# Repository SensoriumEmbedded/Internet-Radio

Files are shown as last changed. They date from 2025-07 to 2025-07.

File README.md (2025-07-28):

# Internet-Radio
ESP32 based WiFi Internet Radio with display, rotary encoder controls, and SD storage

## Stand-alone version:
|||
|--|--|
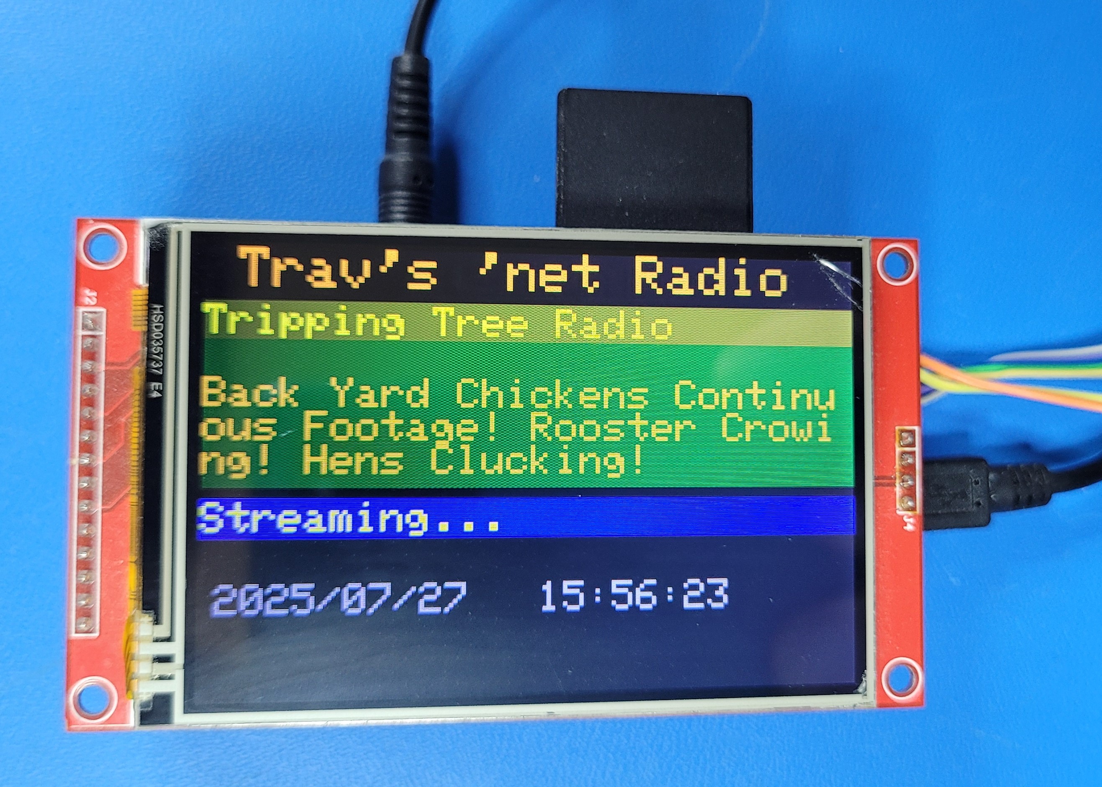
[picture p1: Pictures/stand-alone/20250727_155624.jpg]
Stand-alone front
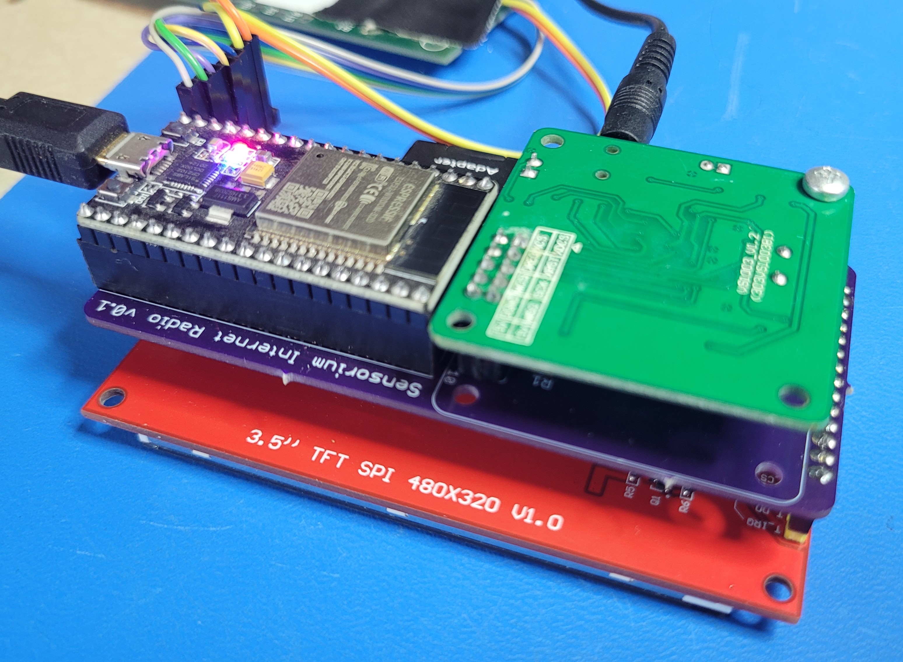
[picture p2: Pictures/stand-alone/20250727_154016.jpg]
Stand-alone back
|||

## Full version incorporated in a 1941 Philco Radio case:
|||
|--|--|
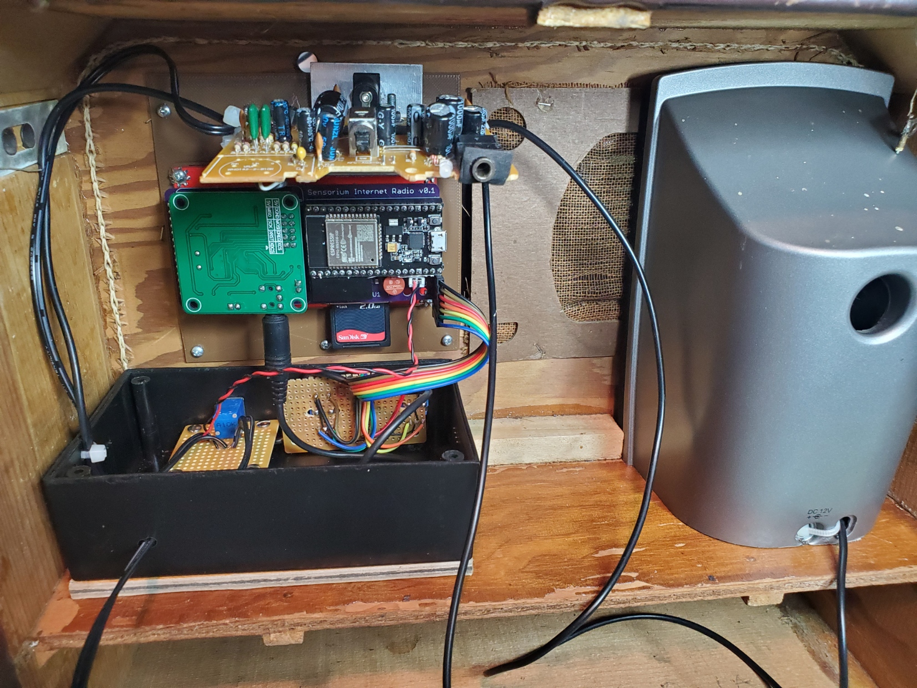
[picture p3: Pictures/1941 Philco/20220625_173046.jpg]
|<video src="Pictures/1941 Philco/Internet Radio_01.mp4" title="1941 Philco project"></video>||

<video controls src="Pictures/1941 Philco/Internet Radio_01.mp4" title="Title"></video>

## Features
* Plays streaming MP3 stations
  * Large buffer for smooth playback
* Parses/displays displays meta data information
* Stores settings and favorite stations on SD card
* Can display pictures (jpg) and play MP3 files
* Displays time, synched from internet connection
* Remote control interface via TTL serial

## Operation
* "S" Rotary Encoder: Push to enter menu system/select.  Rotate to move "cursor"
* "C" Rotary Encoder: Turn (slowly) to select channels, like a dial.  push to stop streaming.
* Scan for wifi and enter a PW in the menu (among other things, explore away).
  * All the settings are saved to "NetRadio.txt" on the SD card. 

## Inspiration
* https://github.com/Edzelf/Esp-radio
* https://github.com/RalphBacon/205-Internet-Radio

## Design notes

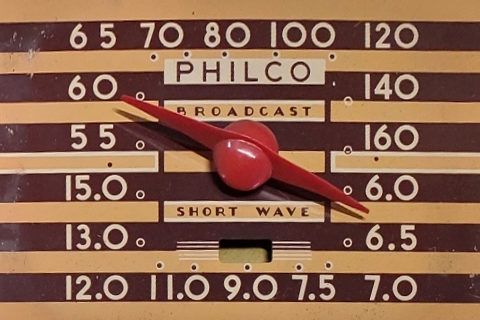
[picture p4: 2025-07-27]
Source/SD Card/DialOnly.jpg

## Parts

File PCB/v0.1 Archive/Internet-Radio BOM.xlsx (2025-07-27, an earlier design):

Part | Value | Source for June 2022 build | Description | DIGIKEY | MANUF1 | MPN1
Required for min config, USB powered:
J2 | VS1053 CoDec | Amazon | HiLetgo VS1053 MP3 Audio Player Module Audio Decoder | Amazon (https://www.amazon.com/HiLetgo-Recording-Microphone-Interface-12-288Mhz/dp/B07XCN3C7B) |  |  | $11.39
J4 | ESP32 | Amazon | HiLetgo ESP-WROOM-32 ESP3 | Amazon (https://www.amazon.com/HiLetgo-ESP-WROOM-32-Development-Microcontroller-Integrated/dp/B0718T232Z) |  |  | $9.99
J5 | TFT Display | Amazon | LCD Screen Module TFT 3.5 inch SPI Serial 480 x 320 ILI9488 | Amazon (https://www.amazon.com/Module-3-5inch-ILI9488-Electronic-Accessories/dp/B08DKNLSNX) | Amazon 2 (https://www.amazon.com/Hosyond-Display-Compatible-Mega2560-Development/dp/B0BWJHK4M6?th=1) |  | $16.99
PBC | PCB v0.1 | OSH Park | Sensorium Internet Radio v0.1
J2-5 | Female Headers | stock | 2x5 and 1x(14+4+19+19=56) female headers
J5b | Male Header | stock | 1x4, solder to display
 | SD Card | stock |  |  |  |  | $3.60
 | Rot Encoders | Digikey |  | Amazon (https://www.amazon.com/WWZMDiB-Encoder-Digital-Potentiometer-Arduino/dp/B0C6Q67V97) | ACZ11BR1E-20FD1-12C | CUI Devices | $2.96
Optional for 9-18Vin external power supply. Includes isolation so same source supply can be used for amp/speakers
C1 | 0.1 uF | stock | Cap, 0805
C2 | 10 uF, 25v | stock | Cap, 0805 | 1276-2890-1-ND
C3 | 47 uF | Mouser | Cap, 0805
D1 | CUS08F30 | Mouser | DIODE SCHOTTKY 30V 800MA USC SOD-323 | CUS08F30H3FTR-ND | Toshiba | CUS08F30,H3F
F1 | 500mA | stock | 500mA Fuse | WK4041BK-ND | Littelfuse Inc | 37405000410
J1 | JST-2POS-2MM | stock | CONN HEADER VERT 2POS 2MM | 455-1704-ND | JST Sales America Inc. | B2B-PH-K-S(LF)(SN)
J3 | 5 pin header | n/a | FEMALE HEADER
R1 | DNS | n/a | Resistor, 0805
U1 | SPAN02A-05 | Mouser | Isolated DC/DC conv

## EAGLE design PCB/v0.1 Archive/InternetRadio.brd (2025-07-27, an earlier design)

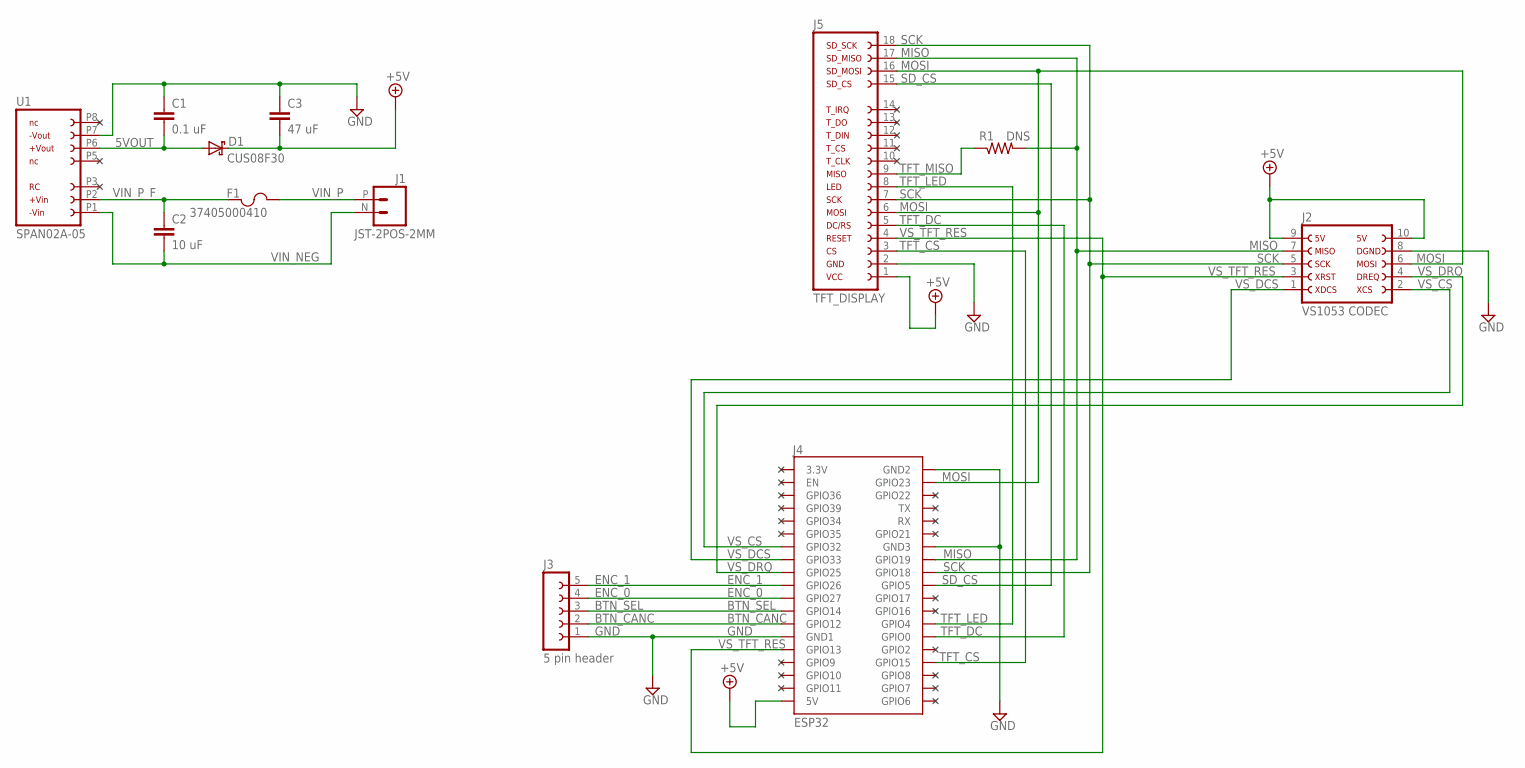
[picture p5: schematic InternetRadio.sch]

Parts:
C1: 0.1 uF; 0805
C2: 10 uF; 0805
C3: 47 uF; 0805
D1: CUS08F30; SOD-323
F1: 37405000410; FUS_LITTELFUSE_374_LTF
J1: JST-2POS-2MM; 89400-0220
J2: VS1053 CODEC; VS1053_MODULE
J3: 5 pin header; FE05-1
J4: ESP32
J5: TFT_DISPLAY; 3.5"_TFT_DISPLAY-NO_HOLES
R1: DNS; 0805
U1: SPAN02A-05

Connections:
5VOUT: C1.2, D1.A, U1.P6 (6)
+5V: C3.2, D1.C, J2.9, J2.10, J4.5V, J5.1
BTN_CANC: J3.2, J4.GPIO12
BTN_SEL: J3.3, J4.GPIO14
ENC_0: J3.4, J4.GPIO27
ENC_1: J3.5, J4.GPIO26
GND: C1.1, C3.1, J2.8, J3.1, J4.GND1, J4.GND2, J4.GND3, J5.2, U1.P7 (7)
MISO: J2.7, J4.GPIO19, J5.17, R1.2
MOSI: J2.6, J4.GPIO23, J5.6, J5.16
SCK: J2.5, J4.GPIO18, J5.7, J5.18
SD_CS: J4.GPIO5, J5.15
TFT_CS: J4.GPIO15, J5.3
TFT_DC: J4.GPIO0, J5.5
TFT_LED: J4.GPIO4, J5.8
TFT_MISO: J5.9, R1.1
VIN_NEG: C2.2, J1.N (1), U1.P1 (1)
VIN_P: F1.1, J1.P (2)
VIN_P_F: C2.1, F1.2, U1.P2 (2)
VS_CS: J2.2, J4.GPIO32
VS_DCS: J2.1, J4.GPIO33
VS_DRQ: J2.4, J4.GPIO25
VS_TFT_RES: J2.3, J4.GPIO13, J5.4

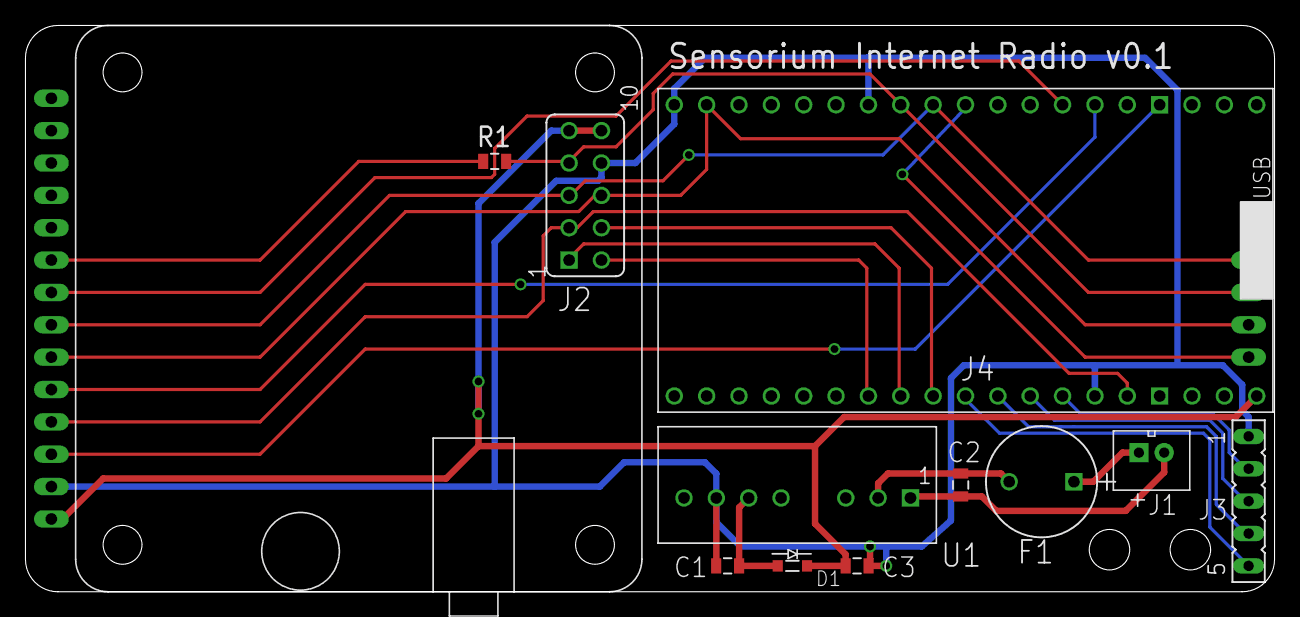
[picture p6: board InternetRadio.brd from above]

Board: 2 copper layers, 98.0 x 44.5 mm, 12 parts (1 on the bottom side), 22 nets.

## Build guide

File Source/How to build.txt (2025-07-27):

How to Build:

  Arduino IDE, v2.3.2 was last used, newer should be fine.
  
  Libraries are included to preserve revision and modification of TFT_eSPI:
   Set sketchbook (lib) location to Source folder (contains /libraries)
  
  Additional board manager:  https://dl.espressif.com/dl/package_esp32_index.json   -or-
                             https://raw.githubusercontent.com/espressif/arduino-esp32/gh-pages/package_esp32_index.json

  Board: "ESP32 Dev Module" (near top of list)  (was NodeMCU-32S)

  7/27/2025 lib info:
    Using library SPI at version 3.0.4 in folder: C:\Users\trav\AppData\Local\Arduino15\packages\esp32\hardware\esp32\3.0.4\libraries\SPI 
    Using library TFT_eSPI at version 2.4.61 in folder: D:\MyData\Geek Stuff\Projects\Internet Radio\Internet-Radio\Source\libraries\TFT_eSPI-2.4.61 
    Using library FS at version 3.0.4 in folder: C:\Users\trav\AppData\Local\Arduino15\packages\esp32\hardware\esp32\3.0.4\libraries\FS 
    Using library SPIFFS at version 3.0.4 in folder: C:\Users\trav\AppData\Local\Arduino15\packages\esp32\hardware\esp32\3.0.4\libraries\SPIFFS 
    Using library VS1053 Library for ESP8266/ESP32 at version 1.1.2 in folder: D:\MyData\Geek Stuff\Projects\Internet Radio\Internet-Radio\Source\libraries\ESP_VS1053_Library 
    Using library WiFi at version 3.0.4 in folder: C:\Users\trav\AppData\Local\Arduino15\packages\esp32\hardware\esp32\3.0.4\libraries\WiFi 
    Using library Networking at version 3.0.4 in folder: C:\Users\trav\AppData\Local\Arduino15\packages\esp32\hardware\esp32\3.0.4\libraries\Network 
    Using library Time at version 1.6.1 in folder: D:\MyData\Geek Stuff\Projects\Internet Radio\Internet-Radio\Source\libraries\Time 
    Using library Bounce2 at version 2.57 in folder: D:\MyData\Geek Stuff\Projects\Internet Radio\Internet-Radio\Source\libraries\Bounce2 
    Using library RotaryEncoder at version 1.5.2 in folder: D:\MyData\Geek Stuff\Projects\Internet Radio\Internet-Radio\Source\libraries\RotaryEncoder 
    Using library SD at version 3.0.4 in folder: C:\Users\trav\AppData\Local\Arduino15\packages\esp32\hardware\esp32\3.0.4\libraries\SD 
    Using library TJpg_Decoder at version 1.0.5 in folder: D:\MyData\Geek Stuff\Projects\Internet Radio\Internet-Radio\Source\libraries\TJpg_Decoder 
    Using library LittleFS at version 3.0.4 in folder: C:\Users\trav\AppData\Local\Arduino15\packages\esp32\hardware\esp32\3.0.4\libraries\LittleFS 
    "C:\\Users\\trav\\AppData\\Local\\Arduino15\\packages\\esp32\\tools\\esp-x32\\2302/bin/xtensa-esp32-elf-size" -A "C:\\Users\\trav\\AppData\\Local\\Temp\\arduino\\sketches\\2D6387340B86BC38645DDF778E6259B7/InternetRadio.ino.elf"
    Sketch uses 1066773 bytes (81%) of program storage space. Maximum is 1310720 bytes.
    Global variables use 124436 bytes (37%) of dynamic memory, leaving 203244 bytes for local variables. Maximum is 327680 bytes.

  Modified for ILI9488_DRIVER, but HX8357D_DRIVER can be used:
    Set Driver in libraries\TFT_eSPI\User_Setup.h
      (comment out one display)
      #define HX8357D_DRIVER   //$40 Blue Adafruit board used on hardwired proto     https://www.adafruit.com/product/2050
      #define ILI9488_DRIVER   //$25 Red board from Amazon     https://www.amazon.com/dp/B08MQLSCRP
      (Pin updates when updating library)
      #define TFT_MISO 19
      #define TFT_MOSI 23
      #define TFT_SCLK 18
      #define TFT_CS   15  // Chip select control pin
      #define TFT_DC    0  //2  // Data Command control pin
      //#define TFT_RST   4  // Reset pin (could connect to RST pin)
      #define TFT_RST  -1  // Set TFT_RST to -1 if display RESET is connected to ESP32 board RST

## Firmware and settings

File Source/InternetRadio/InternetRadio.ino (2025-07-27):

#include <SPI.h>
#include <TFT_eSPI.h>
#include <VS1053.h>
#include <WiFi.h>
#include <TimeLib.h>
#include <WiFiUdp.h>
#include <Bounce2.h>
#include <RotaryEncoder.h>
#include <FS.h>
#include <SD.h>
#include <TJpg_Decoder.h>
#include "InternetRadio.h"

uint32_t LastUpdateMs = millis();
uint16_t StationSelect = 0;
uint16_t BytesUntilMetaData = 0;
uint16_t MetaDataInterval = 0;
char TrackName[MAX_TITLE_LEN] = "";  
bool PrintUpdates = false;  //print periodic updates to USB
bool isStreaming = false;  //Are we Streaming currently?
bool MetaDataPresent = false;    //Meta Data detected in Stream
bool ReConnect = false; //force re-connect from main loop
bool ForceRebuf = false; //force rebuffer on under-run
IPAddress ntpServerIP; // NTP server's ip address, resolved from name at WiFi connect

//these are populated from SD card "/NetRadio.txt" file
char ntpServerName[32] = "us.pool.ntp.org";  // NetTimeProtocol Server name
int timeZone = -7;  //Pacific Daylight Time (USA)
char WiFiSSID[MAX_SSID_CHAR_LEN];
char WiFiPassword[MAX_CHAR_INP_LEN];
StructStationInfo RadioStation[MAX_STATIONS] = {"1940s/50s Radio Retro","64.150.176.42",8098,"/"};
uint16_t NumStations = 1;   // # stations stored
uint16_t CurrentStationNum = 0;  //current station
uint16_t DefaultStationNum = 0;  //Default station
StructStationInfo CurrentStation = RadioStation[CurrentStationNum];

WiFiUDP Udp;
TFT_eSPI tft = TFT_eSPI();
VS1053 player(VS1053_CS_PIN, VS1053_DCS_PIN, VS1053_DREQ_PIN);
WiFiClient client; // Use WiFiClient class to create HTTP/TCP connection
Bounce2::Button SelectButton = Bounce2::Button();
Bounce2::Button CancelButton = Bounce2::Button();

//RotaryEncoder Constructor sets INPUT_PULLUPs
#ifdef PHILCO_1941_RADIO_HW
   RotaryEncoder RotEncSel(ROT_ENC_SEL_1_PIN, ROT_ENC_SEL_0_PIN, RotaryEncoder::LatchMode::FOUR3);
   RotaryEncoder RotEncCanc(ROT_ENC_CANC_0_PIN, ROT_ENC_CANC_1_PIN, RotaryEncoder::LatchMode::FOUR3);
#else
   RotaryEncoder RotEncSel(ROT_ENC_SEL_0_PIN, ROT_ENC_SEL_1_PIN, RotaryEncoder::LatchMode::TWO03);
   RotaryEncoder RotEncCanc(ROT_ENC_CANC_0_PIN, ROT_ENC_CANC_1_PIN, RotaryEncoder::LatchMode::TWO03);
#endif

void setup() 
{
  pinMode(BLUE_LED_PIN, OUTPUT);
  digitalWrite(BLUE_LED_PIN, true); //I'm alive!
  Serial.begin(115200);

  Serial.println("\n\nTrav's ESP32/VS1053 Internet Radio");

  pinMode(VS_TFT_RESET_PIN, OUTPUT);
  digitalWrite(VS_TFT_RESET_PIN, false); //Place the VS1053 and TFT display in reset
  //Drive CS LInes of all SPI devices (except TFT disp) high
  pinMode(VS1053_CS_PIN, OUTPUT);
  digitalWrite(VS1053_CS_PIN, true); 
  pinMode(VS1053_DCS_PIN, OUTPUT); 
  digitalWrite(VS1053_DCS_PIN, true); 
  pinMode(SD_CARD_CS_PIN, OUTPUT); 
  digitalWrite(SD_CARD_CS_PIN, true); 
  delay(10);
  digitalWrite(VS_TFT_RESET_PIN, true); //Release reset

  SPI.begin();

  pinMode(TFT_BACKLIGHT_PIN, OUTPUT); 
  analogWrite(TFT_BACKLIGHT_PIN, 255); //max brightness
  DispInit(); //First SPI dev to init

  player.begin();
  while (!player.isChipConnected()) 
  {
     DispStatus("Couldn't find VS1053");
     player.begin();
     delay(100);
  }
  DispStatus("VS1053 Found");
  
  SDInit(); //todo:  verify success, SD is required
  SDLoadSettings();
  CurrentStationNum = DefaultStationNum;
  CurrentStation = RadioStation[DefaultStationNum];

  SelectButton.attach(SELECT_BUTTON_PIN ,  INPUT_PULLUP); // USE INTERNAL PULL-UP
  SelectButton.interval(5); 
  SelectButton.setPressedState(LOW); 
  CancelButton.attach(CANCEL_BUTTON_PIN ,  INPUT_PULLUP); // USE INTERNAL PULL-UP
  CancelButton.interval(5); 
  CancelButton.setPressedState(LOW); 

  Serial.println("ESP32 Internet Radio");
  Serial.println(VERSION);
  Serial.println("Setup Complete");  
  DispStatus("Setup Complete");  
  digitalWrite(BLUE_LED_PIN, false); // indicates streaming
  
#if SLAVE_MODE
  SerialSlave.begin(115200, SERIAL_8N1, SERIAL2_RXD, SERIAL2_TXD);
  Serial.println("\n*** Slave mode, will not respond to USB Serial commands!");
#else 
  if (WifiConnectDefault()) StreamConnectLoop(); //connect/stream automatically in normal mode
  Serial.println("\nNormal/USB command mode");
#endif

}

void loop()
{ //should be no menu displayed when looping at this top level
  MainLoopWork();

  SelectButton.update();
  if (SelectButton.pressed()) MenuMain();

  CancelButton.update();
  if (CancelButton.pressed()) StopStreaming();  //with no menu, cancel stops streaming
  
  int8_t RotEncCancMove = RotEncCancUpdate();
  if (RotEncCancMove) 
  {  //cancel encoder selects stations
     if (RotEncCancMove == 1)
     {
        if (CurrentStationNum == NumStations - 1) CurrentStationNum = 0; //circular
        else CurrentStationNum++;
     }
     else
     {
        if (CurrentStationNum == 0) CurrentStationNum = NumStations - 1; //circular
        else CurrentStationNum--;
     }
     CurrentStation = RadioStation[CurrentStationNum];
     StreamConnectLoop();
  }
  
  DispCheckUpdateTime();  //only in main loop, displayed in Menu area
}

void MainLoopWork()
{
  if (isStreaming)
  {
    if (player.data_request()) FeedDecoder();
    if (client.available()) ClientReadByte();
    if (ReConnect)
    {
       ReConnect = false;
       StreamConnectLoop();
    }
  }
  PrintUpdate();
  CheckForSerial();
}

void StreamConnectLoop()
{
  uint32_t StartMillis = millis();
  isStreaming = false;  
  digitalWrite(BLUE_LED_PIN, false);
  
  if (WiFi.status() != WL_CONNECTED)
  {
     DispStatus("WiFi Not Connected");
     return;
  }
   
  uint8_t NumTries = 3;
  
  char Stat[MAX_CHARS_PER_LINE + 4] = "try:";
  strcat(Stat, CurrentStation.friendlyName);
  Stat[MAX_CHARS_PER_LINE - 1]=0;  //Terminate at single line, if needed
  DispStatus(Stat);
  DispTrackName("");
  DispCurrentStation("");

  //player.softReset(); //Otherwise gets stuck if changing encoding type (ie ogg/mp3)
  player.switchToMp3Mode();  //avoids VS1053 board rework.   also does .softReset()
  player.loadDefaultVs1053Patches();
  player.setVolume(100);   //0-100, 100 is loudest
  
  Serial.println("Attempting to connect to:");
  Serial.printf("  Name: %s\n", CurrentStation.friendlyName);
  Serial.printf("  Host: %s\n", CurrentStation.host);
  Serial.printf("  Path: %s\n", CurrentStation.path);
  Serial.printf("  Port: %d\n", CurrentStation.port);

  while(NumTries--)
  {
    if (TryStreamConnect())
    {
      isStreaming = true;
      digitalWrite(BLUE_LED_PIN, true);
      DispCurrentStation(CurrentStation.friendlyName);
      DispStatus("Streaming...");
      Serial.printf("Took %d mS to conn to: %s\n", millis() - StartMillis, CurrentStation.friendlyName);
      return;
    }
    else
    {
      Serial.println("*** Connect Failed!\n");
      DispStatus(" Trying again...");
    }
  }
  Serial.println("*** Giving up!");
  DispStatus("Couldn't connect to stream");
}
  
bool TryStreamConnect()
{
  //client.stop();   
  Serial.printf("\nAttempting to connect to: %s\n", CurrentStation.friendlyName);  
 
  if (!client.connect(CurrentStation.host, CurrentStation.port)) 
  {
    Serial.println("Connection failed");
    return false;
  }
  
  Serial.printf("Requesting path: %s\n", CurrentStation.path);
  client.print(String("GET ") + CurrentStation.path + " HTTP/1.1\r\n" +
               "Host: " + CurrentStation.host + "\r\n" + 
               "Icy-MetaData:1\r\n" +
               "Connection: close\r\n\r\n");
  
  if (!ClientAvailableTimeout(3000)) return false;  //wait up to 3 seconds for data to start flowing
  
  MetaDataInterval = 0;
  if (!ReadMetaHeader()) return false;
  MetaDataPresent = (MetaDataInterval != 0);
  if (!MetaDataPresent) 
  {
    Serial.println("* No MetaData detected");
    DispTrackName("<unavailable>");
  }
  
  BytesUntilMetaData = MetaDataInterval;
  return ResetFillBuff();
}

bool WifiConnectDefault()
{
  return WifiConnect(WiFiSSID, WiFiPassword);
}

bool WifiConnect(const char *ssid, const char *password)
{
  if (ssid[0] == 0)
  {
     DispStatus("WiFi fail: No SSID");
     return false;
  }
  StopStreaming();
  DispStatus("Connecting to WiFi");
  Serial.printf("Connecting to SSID %s\n", ssid);
  WiFi.disconnect(); 
  delay(100);  //seems to resolve occasional 0dB RSSI when re-connecing to same (?)
  WiFi.mode(WIFI_STA);
  WiFi.persistent(false);
  WiFi.setSleep(false); // Don't allow WiFi sleep
  WiFi.begin(ssid, password);
  
  uint8_t WaitCycles = 30; //~15 seconds (seeing 5 sec typical)
  while (WiFi.status() != WL_CONNECTED) 
  {
    if (WaitCycles-- == 0)
    {
      Serial.println("* Timeout waiting for Wifi Connect");
      DispStatus("WiFi fail: Timeout!");
      return false;
    }
    delay(500);
    Serial.print(".");
  }
 
  Serial.println("\nWiFi connected");  
  Serial.print("IP address: ");  Serial.println(WiFi.localIP());
  Serial.printf("Signal strength (RSSI): %d dBm\n", WiFi.RSSI());
  if (WiFi.RSSI() == 0) 
  {
    Serial.println("No Signal?");
    DispStatus("WiFi fail: no signal!");
    return false;
  }
  
  DispStatus("Starting UDP");
  Udp.begin(LOCAL_UDP_PORT);
  //Done at connect instead of each synch as this resolution can take >1 sec, causing audio out glitch (though typically <20mS)
  WiFi.hostByName(ntpServerName, ntpServerIP); // get a random server IP from the pool via name
  Serial.printf("Time server: %s     IP: ", ntpServerName);
  Serial.println(ntpServerIP);

  DispStatus("Synching time from 'net");
  setSyncProvider(getNtpTime);
  setSyncInterval(300);  //seconds (300 in example)

  DispStatus("Connected to WiFi");
  return true;
}

/*-------- NTP code ----------*/

const int NTP_PACKET_SIZE = 48; // NTP time is in the first 48 bytes of message
byte packetBuffer[NTP_PACKET_SIZE]; //buffer to hold incoming & outgoing packets

time_t getNtpTime()
{
  Serial.printf("Updating time from: %s      IP: ", ntpServerName);
  Serial.println(ntpServerIP);
  while (Udp.parsePacket() > 0) ; // discard any previously received packets
  sendNTPpacket(ntpServerIP); //only 1-2mS

  uint32_t beginWait = millis();
  while (millis() - beginWait < 1500) 
  {
    if (isStreaming && player.data_request()) FeedDecoder(); //Keep playing from buffer while time being read
    int size = Udp.parsePacket();
    if (size >= NTP_PACKET_SIZE) 
    {
      Udp.read(packetBuffer, NTP_PACKET_SIZE);  // read packet into the buffer
      unsigned long secsSince1900;
      // convert four bytes starting at location 40 to a long integer
      secsSince1900 =  (unsigned long)packetBuffer[40] << 24;
      secsSince1900 |= (unsigned long)packetBuffer[41] << 16;
      secsSince1900 |= (unsigned long)packetBuffer[42] << 8;
      secsSince1900 |= (unsigned long)packetBuffer[43];
      Serial.printf("Received NTP Response in %d mS\n", (millis() - beginWait));  //typical <120 mS or timeout
      return secsSince1900 - 2208988800UL + timeZone * SECS_PER_HOUR;
    }
  }
  Serial.println("NTP Response timeout");
  return 0; // return 0 if unable to get the time
}

// send an NTP request to the time server at the given address
void sendNTPpacket(IPAddress &address)
{
  // set all bytes in the buffer to 0
  memset(packetBuffer, 0, NTP_PACKET_SIZE);
  // Initialize values needed to form NTP request
  // (see URL above for details on the packets)
  packetBuffer[0] = 0b11100011;   // LI, Version, Mode
  packetBuffer[1] = 0;     // Stratum, or type of clock
  packetBuffer[2] = 6;     // Polling Interval
  packetBuffer[3] = 0xEC;  // Peer Clock Precision
  // 8 bytes of zero for Root Delay & Root Dispersion
  packetBuffer[12] = 49;
  packetBuffer[13] = 0x4E;
  packetBuffer[14] = 49;
  packetBuffer[15] = 52;
  // all NTP fields have been given values, now
  // you can send a packet requesting a timestamp:
  Udp.beginPacket(address, 123); //NTP requests are to port 123
  Udp.write(packetBuffer, NTP_PACKET_SIZE);
  Udp.endPacket();
}

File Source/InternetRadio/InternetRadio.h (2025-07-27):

#define SLAVE_MODE     false   //if true, All input and some output routes from/to SerialSlave instead of USB serial 
//#define PHILCO_1941_RADIO_HW            //if defined, use settings for 1941 Philco Radio build

#define VERSION "0.80"
// v0.80  2021/06/20: basic remote functions implemented, versioninng start

#define LOCAL_UDP_PORT       8888 // local port to listen for UDP packets

//      TFT_MISO           19   // Set in libraries\TFT_eSPI\User_Setup.h
//      TFT_MOSI           23   // Set in libraries\TFT_eSPI\User_Setup.h
//      TFT_SCK            18   // Set in libraries\TFT_eSPI\User_Setup.h
//      TFT_CS             15   // Set in libraries\TFT_eSPI\User_Setup.h
//      TFT_DC_RS           0   // Set in libraries\TFT_eSPI\User_Setup.h
#define TFT_BACKLIGHT_PIN   4   // Backlight PWM pin
#define SD_CARD_CS_PIN      5
#define VS_TFT_RESET_PIN   13   //Reset of VS1053 and TFT Display
#define VS1053_CS_PIN      32   // VS1053 chip select pin (output)
#define VS1053_DCS_PIN     33   // VS1053 Data/command select pin (output)
#define VS1053_DREQ_PIN    25   // VS1053 Data request, ideally an Interrupt pin
#define CANCEL_BUTTON_PIN  12
#define SELECT_BUTTON_PIN  14
#define ROT_ENC_SEL_0_PIN  27
#define ROT_ENC_SEL_1_PIN  26
#define ROT_ENC_CANC_0_PIN 21
#define ROT_ENC_CANC_1_PIN 22
#define BLUE_LED_PIN        2   //On-board Blue LED

#if SLAVE_MODE
   #define SERIAL2_RXD    16      //pindef for Serial2
   #define SERIAL2_TXD    17      //pindef for Serial2
   #define SerialSlave    Serial2 //control interface 
#else
   #define SerialSlave    Serial  //Standard USB 
#endif

//***** Display Related *****

//display is 480x320
#define DISP_PIX_PER_LINE      26
#define DISP_MENU_HEIGHT       (4 * DISP_PIX_PER_LINE + 2)    //  54
#define DISP_STATUS_HEIGHT     (1 * DISP_PIX_PER_LINE + 2)    //  28
#define DISP_STATION_HEIGHT    (1 * DISP_PIX_PER_LINE + 2)    //  28
#define DISP_TRACK_NAME_HEIGHT (4 * DISP_PIX_PER_LINE + 2)    // 132 

#define DISP_MENU_TOP          (320 - DISP_MENU_HEIGHT) // at bottom
#define DISP_STATUS_TOP        (DISP_MENU_TOP - DISP_STATUS_HEIGHT - 7) // over Station name, with gap
#define DISP_TRACK_NAME_TOP    (DISP_STATUS_TOP - DISP_TRACK_NAME_HEIGHT - 7) // over status, with gap
#define DISP_STATION_TOP       (DISP_TRACK_NAME_TOP - DISP_STATION_HEIGHT) // over track name

#define DISP_BACK_COLOR        TFT_BLACK   //TFT_PURPLE
#define STATUS_FONT_COLOR      TFT_YELLOW
#define STATUS_BACK_COLOR      TFT_BLUE
#define TIME_FONT_COLOR        TFT_LIGHTGREY
#define MENU_FONT_COLOR        TFT_BLACK
#define MENU_TITLE_COLOR       TFT_WHITE
#define MENU_BACK_COLOR        TFT_DARKGREY
#define MENU_SELECT_FONT_COLOR TFT_BLACK
#define MENU_SELECT_BACK_COLOR TFT_SKYBLUE
#define STATION_FONT_COLOR     TFT_YELLOW
#define STATION_BACK_COLOR     TFT_OLIVE
#define HEADLINE_FONT_COLOR    TFT_ORANGE
#define TRACKNAME_FONT_COLOR   TFT_GOLD
#define TRACKNAME_BACK_COLOR   TFT_DARKGREEN

#define MENU_CANCEL            -1  //Menu return code if not index to menu item
#define MENU_OK                -2  //Menu return code if valid, but not index to menu item
#define MENU_DIR_SEL           -3  //directory selected in file select menu
#define MENU_FILE_SEL          -4  //file selected in file select menu
#define MENU_UP_DIR            -5  //Up level directory selcted

#define MAX_CHAR_INP_LEN       21  //used for WiFi PW and other char string inputs, including term char
#define MAX_SSID_CHAR_LEN      34  //Max SSID length stored, incl term. Spec max is 32 chars
#define MAX_CHARS_PER_LINE     27  //26 chars in display line (plus term) 

#ifdef PHILCO_1941_RADIO_HW
   #define DISP_ORIENTATIOM        1 //1=SD card down
#else
   #define DISP_ORIENTATIOM        3 //3=SD card up (easier for stand-alone use)
#endif

#define UP_DIR_STRING          "/..<up dir>"

#define SETTINGS_FILE_NAME     "/NetRadio.txt"
#define MAX_TITLE_LEN          500 //max length for full/raw Song Title Meta Data (beyond will be terminated)
#define MAX_TRACK_CHARS        104 //Trim final to, 4 lines * 26 chars in display line

#define MAX_STATIONS            50 //max number of stations stored

struct StructMenuItem
{
  char name[MAX_CHARS_PER_LINE];
  void (*call_function)();
};

struct StructStationInfo
{
    char friendlyName[MAX_CHARS_PER_LINE]; 
    char host[64];
    uint16_t port;
    char path[64];
};

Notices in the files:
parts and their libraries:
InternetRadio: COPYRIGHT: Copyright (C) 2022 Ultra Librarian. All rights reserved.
